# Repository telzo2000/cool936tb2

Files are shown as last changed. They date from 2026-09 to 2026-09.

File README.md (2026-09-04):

# cool936tb2

cool936tb2(choc model)
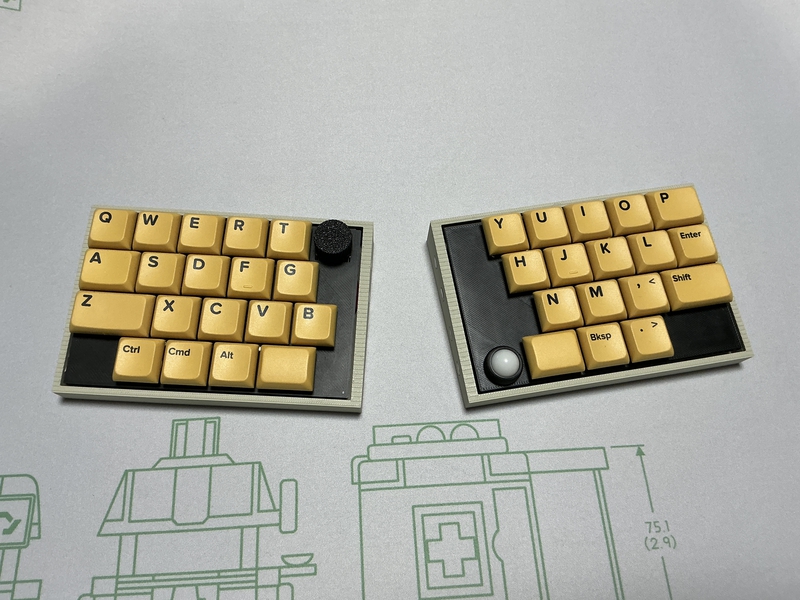
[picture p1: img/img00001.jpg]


cool936tb2(cherry MX model)
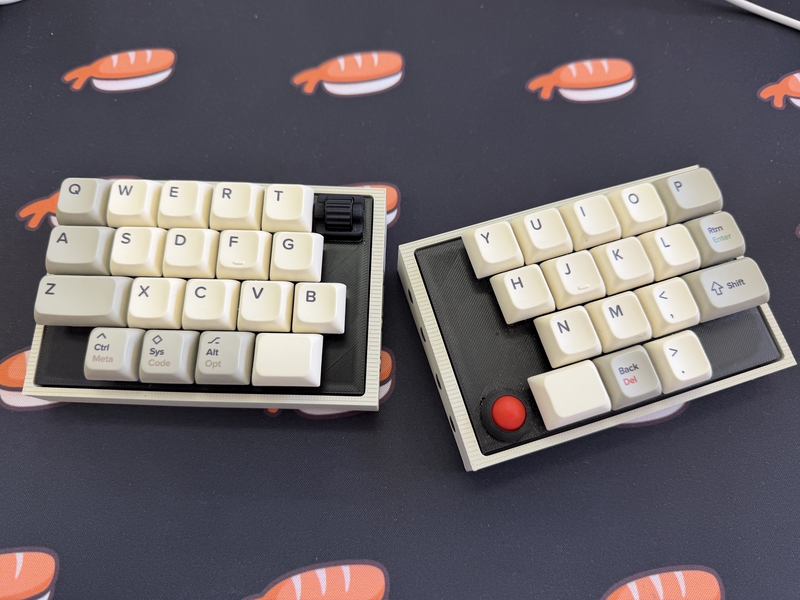
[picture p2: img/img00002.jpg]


## What is cool936tb2?

cool936tb2 is small keyboard with trackball.
<br>
cool936tb2 is splite keyboards.
<br>
cool936tb2 use seeed xiao ble,run zmk_firmware.
<br>
<br>

## firmware

[zmk-config](https://github.com/telzo2000/zmk-config-cool936tb2)

<br>
keymap editor

https://nickcoutsos.github.io/keymap-editor/

<br>
zmk studio

https://zmk.studio/

<br>

自作キーボードへのzmk_firmwareのインストールについて

https://sizu.me/m_ki/posts/kvixkn2mec6a

<br>
zmk_firmwareでのキーマップ編集について

https://sizu.me/m_ki/posts/m3devs7be5km

<br>

## buildguide

https://github.com/telzo2000/cool936tb2/blob/main/buildguide_for_cool936tb2.md

<br>

## BOM

<b>common parts</b>
| No. | Patrs | Quantity | remarks | Suppliers | Cost |
|--|--|--|--|--|--|
|番号|名前|数|備考|調達先|参考価格（送料込）|<br>
|1|PCB|3|Rightside,Leftside,<br>Trackball|[elecrow](https://www.elecrow.com)<br>[JLCPCB](https://jlcpcb.com)<br>[ALLPCB](https://www.allpcb.com)||<br>
|2|Switch plate|2|3D Print|||
|3|Bottom plate|2|3D Print|||
|4|Ball case|1|3D Print|||
|5|pinheader<br>ピンヘッダ|1|7pin|||
|6|Slide switch<br>スライドスイッチ|2||[秋月電子](https://akizukidenshi.com/catalog/g/g115370/)|１個30円|
|7|AAAA Battery case<br>単４電池ケース|2||[マルツオンライン](https://www.marutsu.co.jp/pc/i/59151/?srsltid=AfmBOoo5ctOn9kOUGJA7pCL4M2f4Y3IolfSweL7epFytDI-BLKNBKMa8)|１個81円|
|8|XIAO nRF52840|2|MCU Board|[seeed studio](https://jp.seeedstudio.com/Seeed-XIAO-BLE-nRF52840-p-5201.html?msclkid=5541f7f3d0f911eca6023fe520de5bfa)<br>[秋月電子](https://akizukidenshi.com/catalog/g/g117341/)|1940円|
|9|Trackball<br>トラックボール|1|12mm級|[アリエク](https://ja.aliexpress.com/item/1005006482041609.html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))等|100円ほど|
|10|PWM3610|1|Trackball senser|[アリエク](https://ja.aliexpress.com/item/1005007622547772.html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)|1000円ぐらい|
|11|Rotery Encoder<br>ロータリーエンコーダー|1|EC12互換|||
|12|Knob<br>ロータリーエンコーダー用ノブ|1|直径19mm以下のもの|||
|13|リセットスイッチ（タクトスイッチ）|2||[秋月電子](https://akizukidenshi.com/catalog/g/g108073/)|１個20円|
|14|ベアリング|3|幅2.5mm 外径5mm|[Amazon](https://www.amazon.co.jp/dp/B00MQELIG8?ref=ppx_yo2ov_dt_b_fed_asin_title)|１個300円程度|
<br>

<b>If you use choc switch...</b>
| No. | Patrs | Quantity | remarks | Suppliers | Cost |
|--|--|--|--|--|--|
|15|Diode<br>ダイオード|37|SMD|[遊舎工房](https://yushakobo.jp)<br>[Talp Keyboard](https://talpkeyboard.net)<br>[Daily Craft Keyboard](https://shop.dailycraft.jp)等|100個で220円程度から|
|16|Swith socket<br>スイッチソケット|36|choc|[遊舎工房](https://yushakobo.jp)<br>[Talp Keyboard](https://talpkeyboard.net)<br>[Daily Craft Keyboard](https://shop.dailycraft.jp)等|10個で165円程度|
|17|Screw<br>ネジ|8|スリムヘッドM2 5mm|[遊舎工房](https://shop.yushakobo.jp/products/a0800s2?variant=37665432535201)|50本880円(遊舎工房)|
|18|Screw<br>ネジ|8|M2 4mm|DIY shop|10本200円程度|
|19|Spacer<br>スペーサー|8|M2 6mm|DIY shop|10本400円程度|
|20|Keyswitch<br>キースイッチ|36|chocV1及びV2対応|[遊舎工房](https://yushakobo.jp)<br>[Talp Keyboard](https://talpkeyboard.net)<br>[Daily Craft Keyboard](https://shop.dailycraft.jp)|１個100程度|
|21|Keycap<br>キーキャップ|36|ロープロが最適|[遊舎工房](https://yushakobo.jp)<br>[Talp Keyboard](https://talpkeyboard.net)<br>[Daily Craft Keyboard](https://shop.dailycraft.jp)||

<br>

<b>If you use cherryMX switch...</b>
| No. | Patrs | Quantity | remarks | Suppliers | Cost |
|--|--|--|--|--|--|
|15|Diode<br>ダイオード|37|SMDまたはリードタイプ|[遊舎工房](https://yushakobo.jp)<br>[Talp Keyboard](https://talpkeyboard.net)<br>[Daily Craft Keyboard](https://shop.dailycraft.jp)等|100個で220円程度から|
|16|Swith socket<br>スイッチソケット|36|cherry MX|[遊舎工房](https://yushakobo.jp)<br>[Talp Keyboard](https://talpkeyboard.net)<br>[Daily Craft Keyboard](https://shop.dailycraft.jp)等|10個で165円程度|
|17|Screw<br>ネジ|8|M2 8mm|DIY shop|10本200円程度|
|18|Screw<br>ネジ|8|M2 4mm|DIY shop|10本200円程度|
|19|Spacer<br>スペーサー|8|M2 6mm|DIY shop|10本400円程度|
|20|Keyswitch<br>キースイッチ|36|cherry MX|[遊舎工房](https://yushakobo.jp)<br>[Talp Keyboard](https://talpkeyboard.net)<br>[Daily Craft Keyboard](https://shop.dailycraft.jp)|１個100程度|
|21|Keycap<br>キーキャップ|36|cherry MX互換|[遊舎工房](https://yushakobo.jp)<br>[Talp Keyboard](https://talpkeyboard.net)<br>[Daily Craft Keyboard](https://shop.dailycraft.jp)||
<br>

<br>

In addition, NiHM rechargeable batteries (4 AAA size), USB cable, etc. are required.
<br>
この他に、NiHM充電池（単４形４本）、USBケーブル等が必要です。
<br>

<br>

# license

[CC BY-NC-SA](https://creativecommons.org/licenses/by-nc-sa/4.0/deed.ja)



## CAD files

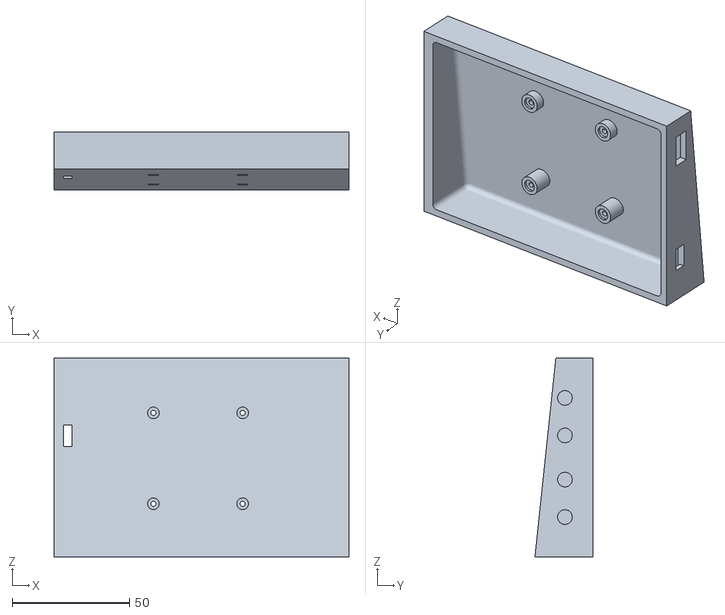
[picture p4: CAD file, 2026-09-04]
casedesign_for_cool936tb2/cool936tb2_MX_L_bottomcase.stl
125.9 x 24.8 x 84.8

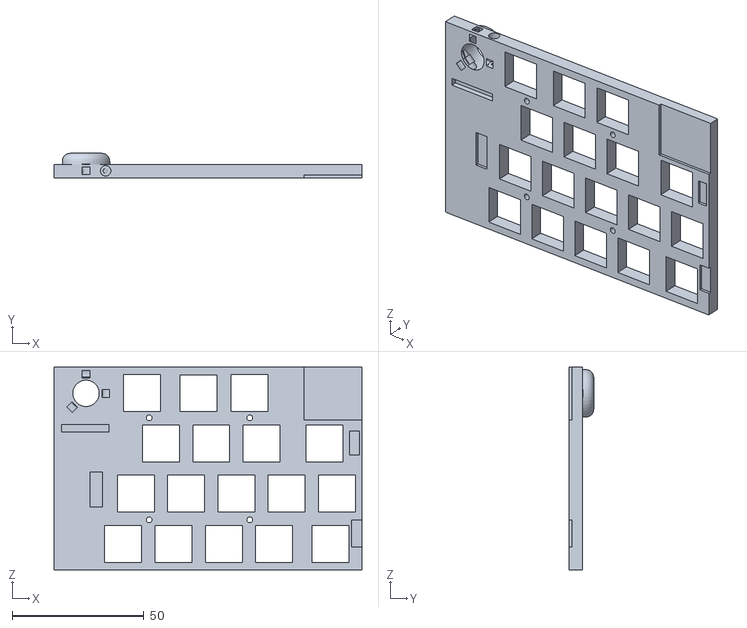
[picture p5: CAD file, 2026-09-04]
casedesign_for_cool936tb2/MX_model/cool936tb2_MX_R_switchplate.stl
116.7 x 9.31 x 76.8

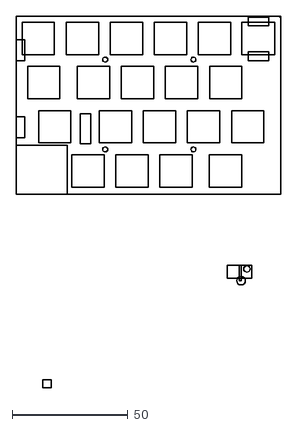
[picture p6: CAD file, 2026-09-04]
casedesign_for_cool936tb2/cool936tb21_L_MX-User_Eco1.dxf
114.3 x 160.3

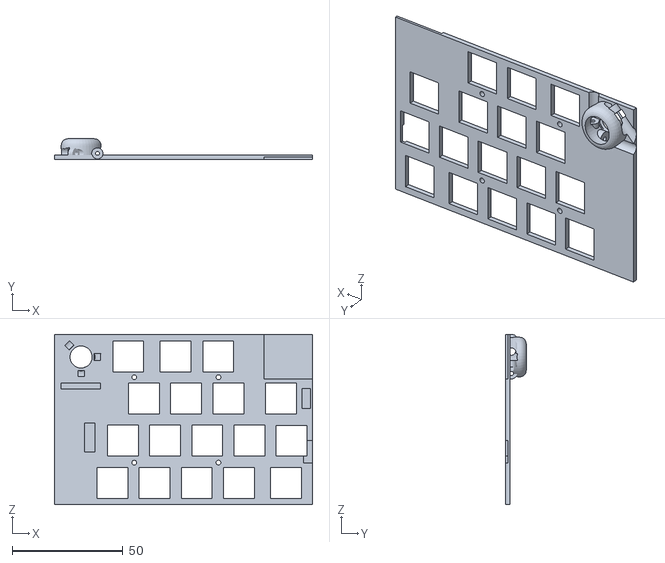
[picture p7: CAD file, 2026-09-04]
casedesign_for_cool936tb2/cool936tb2_R_switchplate_v2.stl
116.7 x 9.31 x 76.9

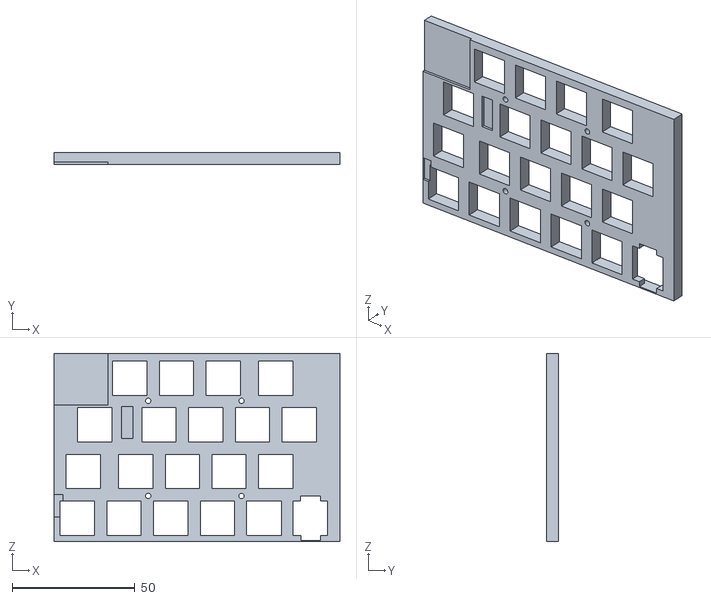
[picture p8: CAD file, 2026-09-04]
casedesign_for_cool936tb2/MX_model/cool936tb2_MX_L_switchplate.stl
116.7 x 5.00 x 76.8

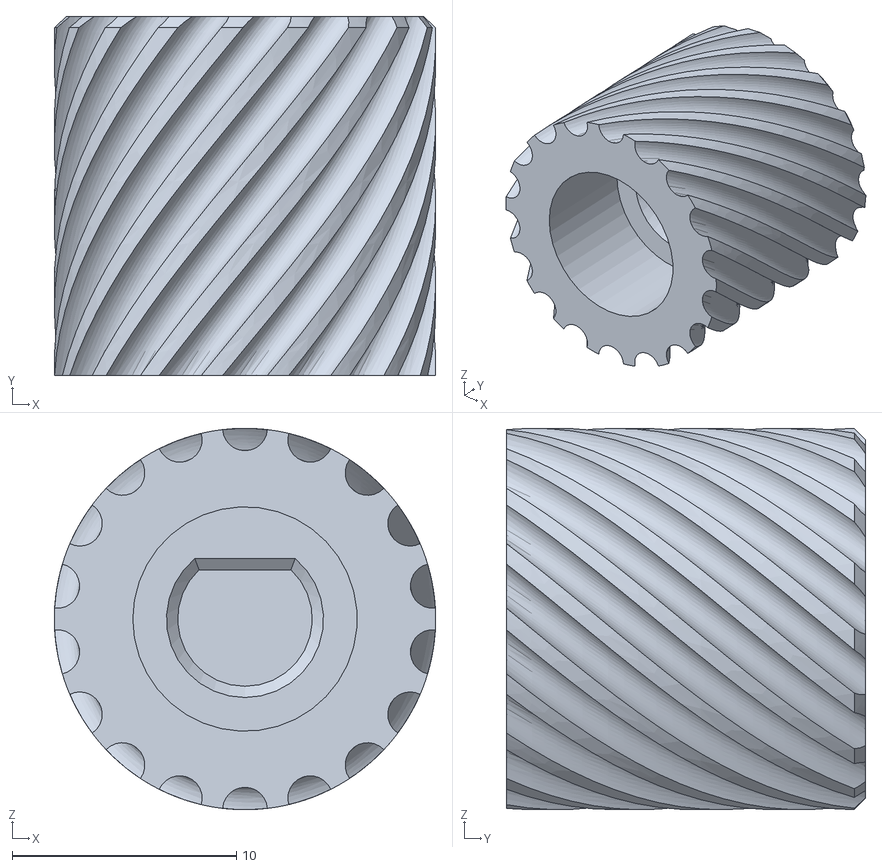
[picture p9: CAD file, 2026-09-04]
casedesign_for_cool936tb2/rotery_encoder_knob_17mmx10mm.stl
17.0 x 16.0 x 17.0

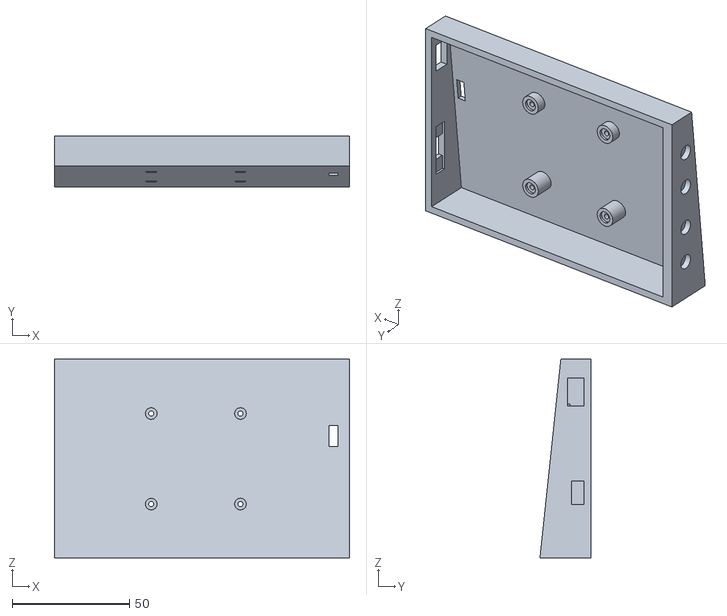
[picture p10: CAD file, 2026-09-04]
casedesign_for_cool936tb2/cool936tb_case_design v40.stl
125.9 x 21.8 x 84.8

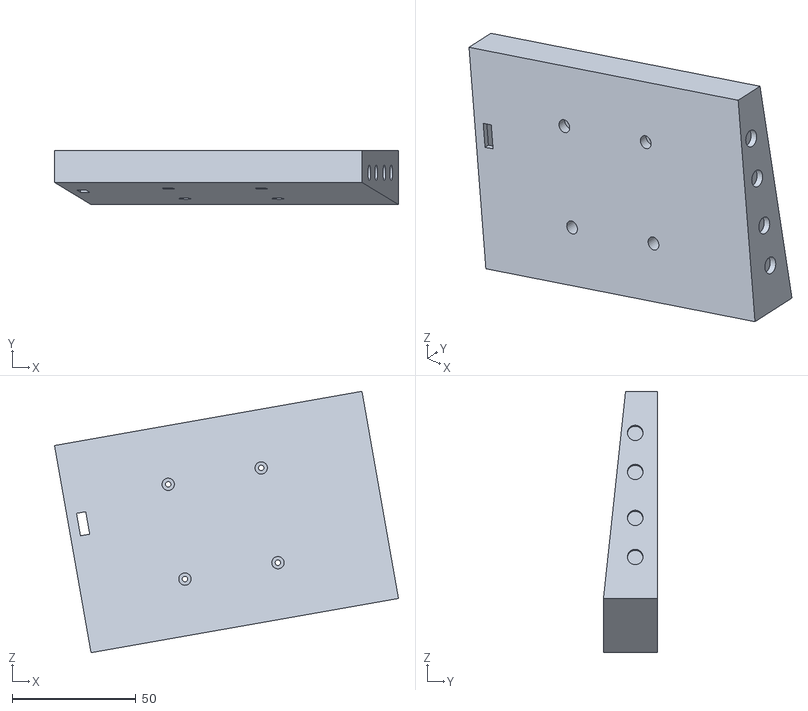
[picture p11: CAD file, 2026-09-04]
casedesign_for_cool936tb2/cool936tb2_left_bottomcase.stl
138.7 x 21.8 x 105.4

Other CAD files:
casedesign_for_cool936tb2/MX_model/cool936tb2_MX_R_bottomcase.stl
casedesign_for_cool936tb2/MX_model/cool936tb2_MX_L_bottomcase.stl

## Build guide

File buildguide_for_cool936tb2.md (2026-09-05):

# ビルドガイド

注意：日本語だけです。
<br>

## 1 基板の向きについて

左右の基板について、「cool936tb2」と印刷がある方が裏面となります。
<br>
トラックボール基板（以下、「トラボ基板」）は、「Back side」と書かれた方が裏面です。
<br>
<br>

## 2 ダイオードのはんだ付け

SMDダイオードが最適です。
<br>
ダイオードには向きがあります。
<br>
PCBA（工場ではんだ付け済み）されているので、実際ははんだ付け不要です。
<br>
<br>

## 3 スイッチソケットのはんだ付け

choc modelは、chocのスイッチソケットを36個用意してはんだ付けをしてください。
<br>
cherry MX modelは、PCBAされているので、はんだ付け不要です。
<br>
<br>

## 4 xiao bleのはんだ付け

このキーボードの最難関なところです。
<br>
次の動画を見ながら、頑張ってください。
<br>

https://youtu.be/98yqLjzfdl4

xiao bleは、左右の基板の裏面にはんだ付けします。
<br>

## 5 トラボ基板のはんだ付け

トラボ基板の「Back side」と書かれた方から、PMW3610センサーを差し込みます。
<br>
「Front side」側に出た端子をはんだ付けします。
<br>
<br>

## 6　リセットスイッチのはんだ付け

リセットスイッチを左右の基板の裏面から差し込みます。
<br>
基板の表面に出た端子をはんだ付けします。
<br>
次の動画を参考にしてください。

https://youtu.be/Pl24Exfh8b8

<br>
<br>

## 7 スライドスイッチのはんだ付け

スライドスイッチを左右の基板の裏面から差し込みます。
<br>
基板の表面に出た端子をはんだ付けします。
<br>
次の動画を参考にしてください。

https://youtu.be/5nkRklibay4

<br>
<br>

## 8 トラボ基板のはんだ付け

う〜ん、動画のストックがないなぁ。

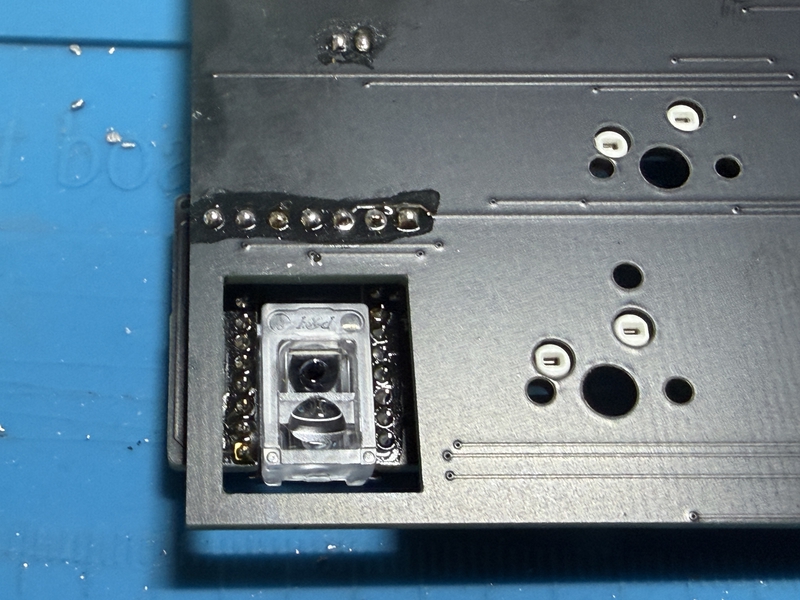
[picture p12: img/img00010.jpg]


<br>
７ピンに長さを調整したピンヘッダを、トラボ基板の「Front side」と書かれた表面から差し込みます。

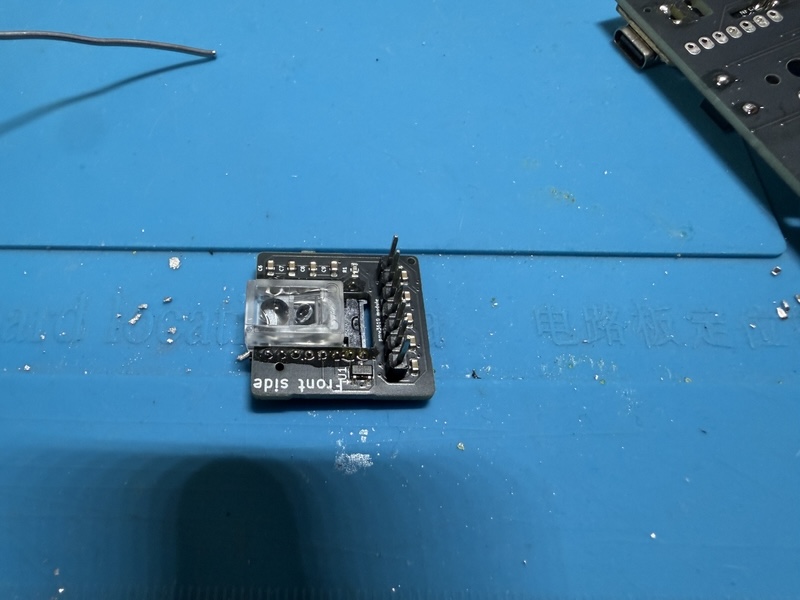
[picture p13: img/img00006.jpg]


裏面に出たピンをはんだ付けします。
<br>
「Front side」と書かれた面に出ているピンヘッダを、右の基板の裏面に差し込みます。

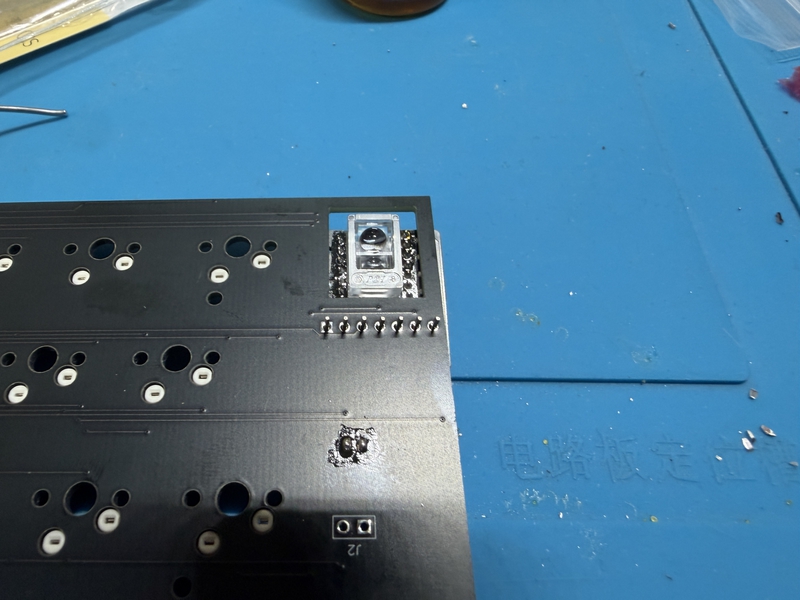
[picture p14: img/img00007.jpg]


出過ぎたピンはニッパーなどで切り取ってください。その後、はんだ付けをします。

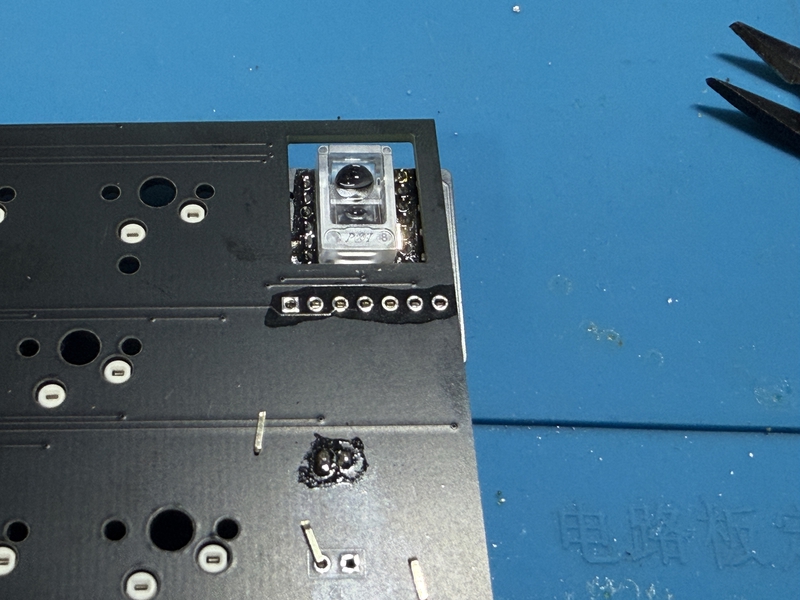
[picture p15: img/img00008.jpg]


横から見て、トラボ基板と右の基板が平行になるように、はんだ付けをしてください。

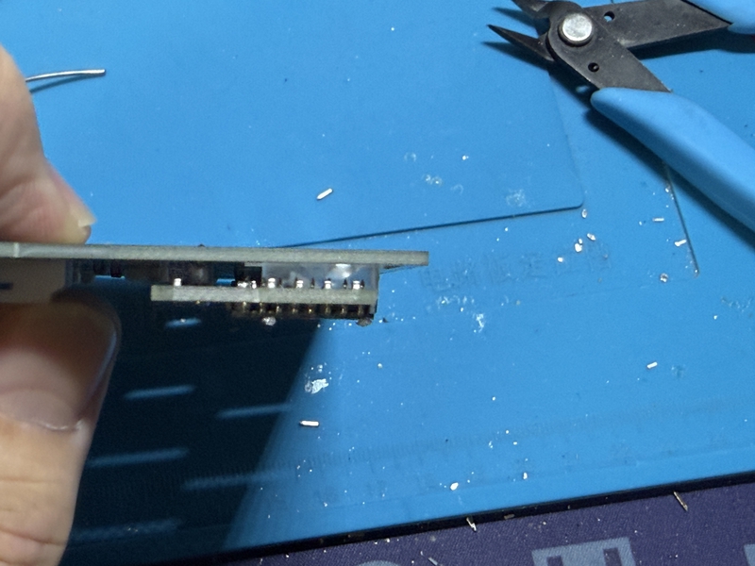
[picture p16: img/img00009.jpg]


<br>
<br>

## 9 電池ケースの接続

JSTコネクター（オス・メス）を使う方法もあります。
<br>
ただし、部品数が増えるため、BOMには載せていません。
<br>
ここでは、電池ケースの赤と黒のケーブルを左右の基板に直にハンダで固定する方法です。
<br>
赤ケーブルは、BAT+に、黒ケーブルは、GNDと左右の基板の裏面に書かれたスルーホール（穴）に差し込んでください。
<br>
表面に出た部分をはんだ付けします。
<br>
電池の逆向きに入れたり、ケーブルの色を間違えて半田付けすると、xiao bleが壊れる可能性があります。
<br>
また、電池ケースに電池を入れた後、スライドスイッチのオンオフに関係なく、xiao bleが発熱した時は、すぐに電池を取り外してください。
<br>
原因として、xiao bleのはんだ付けのミスが考えられます。
<br>
左右の基板の表面からxiao bleを対して、三つの間口があります。その真ん中の間口のはんだ付けがミスしているでしょう。
<br>
ルーペで確認して、BAT+とBAT-がハンダでブリッジ（つながっている状態）していないか、確認してください。
<br>
<br>

## 10 トラックボールユニットの組み立て

右のスイッチプレートにある、トラックボール部分に、上面から内側の窪みに、ベアリングを挿入します。
 <br>
次に、側面から、M2ねじ6mmで固定します。これを３箇所を行ってください。
<br>
その後、上面から、12mm球を軽い力で押し込みます。もし、取り出す時は、下面から押し出してください。
<br>
<br>

## 11　動作確認

スイッチプレートやロータリーエンコダーを装着する前ですが、一度、全てのスイッチソケットのはんだ付けに問題がないか、確認します。
<br>
全てのスイッチソケットにキースイッチを差し込んでください。
<br>
左右の基板にはんだ付けしたxiao bleに、firmwareをドラッグ&ドロップしてください。
<br>
次に電池ケースに単４電池を装着してください。
<br>
左、右の順でスライドスイッチを手前に動かすと電源が入ります。
<br>
お手元のPCやタブレットなどにBT接続して、キー入力が問題なくできるか、確認してください。
<br>
ここで、キー入力が正しく反応しない場合、xiao bleのはんだ付けのミスまたは、ダイオードやスイッチソケットのはんだ付けミス、単純にスイッチソケットに差し込んだキースイッチの端子が曲がっていて、正しく刺さっていない可能性があります。
<br>
動作確認に問題がなければ、キースッチをスイッチソケットから外してください。
<br>
<br>

## 12　ロータリーエンコーダの取り付け

自作キーボードに使用される頻度がある、垂直型のロータリーエンコーダを左の基板に取り付けできます。
<br>
ただし、スイッチプレートの形状が合わない場合、ご自身で加工する必要があります。
<br>
<br>
cherry MX modelでは、水平型のロータリーエンコーダの取り付けを推奨しています。
<br>
遊舎工房で販売されている[CKW12](https://shop.yushakobo.jp/products/ckw12?shop_sign_in=true&variant=51526931153127)が使用できます。
<br>
または、m.ki設計の互換品も取り付け可能です。
<br>
水平型ロータリーエンコーダについては、左のスイッチプレートを左の基板に乗せてから、差し込みます。
<br>
基板の裏面に出た端子をはんだ付けしてください。
<br>
この後、ロータリーエンコーダの動作確認をしてください。
<br>

## 13 スイッチプレートの組み立て

左右の基板に対して、左右のスイッチプレートを上面に乗せます。
<br>
上面からM2ねじを差し込んで、基板の裏面にM2スペーサーで固定してください。
<br>
<br>

## 14 ボトムケースの組み立て

左右のボトムケース内部に、電源スイッチノブを装着します。
<br>
13で組み立てた左右の基板等を、ボトムケースに収めます。
<br>
ケースに収める際、基板のスライドスイッチが、電源スイッチの部の凹部に入れるように注意してください。
<br>
電池ケースをボトムケースの奥側に収められるようして、左右の基板等で蓋をしてください。
<br>
ボトムケースの下面から、M2ネジを差し込み、固定してください。
<br>
左右のボトムケースが向かい合う側面には、厚み2.5mm、直径6mmの丸型磁石が入る凹部があります。
<br>
磁石を入れることで、左右のケースを一体型のように固定できます。
<br>
<br>

## 15　キーキャップの装着

お好みのキーキャップを装着してください。
<br>
下記のサイトは、オリジナルのキーキャップを作れるYUZU Custom Keycapsにおける、キーキャップセットです。
<br>

https://yuzukeycaps.com/ja/c/1da72466-d7d6-40e2-adac-48b55c5aeff5

<br>

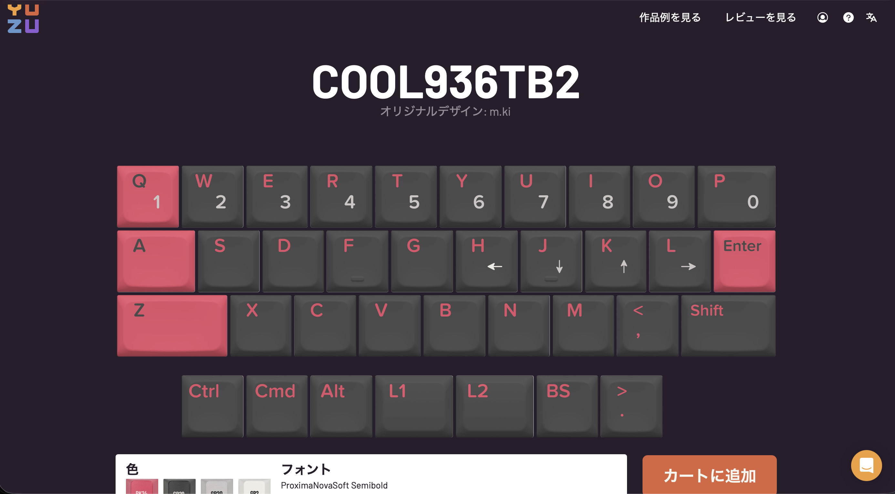
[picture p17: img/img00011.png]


これで完成です。
<br>
<br>
